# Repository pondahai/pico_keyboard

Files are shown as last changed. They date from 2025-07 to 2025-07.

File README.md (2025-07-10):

# Pico 8x8 矩陣鍵盤韌體

這是一個基於 Raspberry Pi Pico (RP2040) 的 8x8 (64鍵) 自訂機械鍵盤韌體專案。它使用 Arduino-Pico 核心，並透過 74HC595 和 74HC165 晶片來擴展 I/O，僅用 3 個 GPIO 引腳就完成了 64 個按鍵的掃描。此外，還額外擴展了 2 個 LED 指示燈。

韌體最終將 Pico 模擬成一個標準的 USB HID 鍵盤，可以被任何現代作業系統即插即用，同時保留了方便的序列埠除錯功能。

**「這句話就是用這個鍵盤輸入的」** —— 專案成功的最好證明！


## ✨ 主要功能

*   **高效 I/O 擴展**：僅用 3 個 Pico GPIO 引腳驅動 8x8 (64鍵) 矩陣和 2 個 LED。
*   **USB HID 鍵盤**：被電腦識別為標準鍵盤，隨插即用。
*   **複合式 USB 裝置**：同時啟用鍵盤功能和序列埠，方便即時除錯。
*   **雙模式系統**:
    *   **正常打字模式**: 作為一個標準鍵盤工作。
    *   **除錯模式**: 透過序列埠輸出按鍵的物理座標 `(row, col)`，極大地方便了 Keymap 的配置與修改。
*   **韌體層級熱鍵**：使用 `右Shift` + `左Ctrl` 組合鍵在兩種模式間自由切換。
*   **LED 狀態指示**:
    *   LED 1: （目前留空，可自訂，例如用於 CapsLock 指示）。
    *   LED 2: 指示當前是否處於除錯模式（亮起 = 除錯模式）。
*   **全鍵無衝 (NKRO)**：底層支援 6-Key Rollover，可透過修改 HID 報告描述符實現全鍵無衝。
*   **高度客製化**: 使用者可以透過修改 `keymap` 陣列輕鬆定義自己的按鍵佈局。
*   **可靠的掃描邏輯**:
    *   採用「二段式脈衝」確保掃描時序穩定。
    *   第一段脈衝給595輸出 第二段脈衝給165載入 
    *   針對 74HC165 的特性自訂 `shiftIn` 邏輯，避免丟失數據。
    *   對硬體掃描數據進行「水平鏡像」，使 `keymap` 的定義符合物理直覺。

## ⚙️ 硬體需求

### 主要元件
*   Raspberry Pi Pico (或任何 RP2040 開發板)
*   1 x 74HC595 (8位元移位暫存器，用於行掃描輸出)
*   1 x 74HC165 (8位元並行輸入移位暫存器，用於列讀取)
*   2 x D型正反器 (或第二顆 74HC595，用於擴展 LED 輸出)
*   8x8 矩陣鍵盤 (64個按鍵和二極體)
*   2 x LED 指示燈
*   下拉電阻 (為 74HC165 的每個輸入引腳配置)

### GPIO 連接

| Pico GPIO | 連接目標 | 功能描述 |
| :--- | :--- | :--- |
| **GP15**  | 74HC595 的 `DS` (Serial Data In) | 數據輸出 (Pico -> 595) |
| **GP14**  | 74HC595 `RCLK` **和** 74HC165 `nPL` (共用) | 鎖存輸出 (上升緣) / 並行加載輸入 (低電位) |
| **GP26**  | 74HC595 `SHCP` **和** 74HC165 `SHCP` (共用) | 共用的移位時脈 |
| **GP27**  | 74HC165 的 `Q7` (Serial Data Out) | 數據輸入 (165 -> Pico) |

### 晶片串接
*   **輸出鏈 (595)**: `Pico GP15` -> `595(IC1) DS` -> `595(IC1) Q7'` -> `DFF(IC2) D` -> ...
*   **時脈與鎖存**：所有晶片的時脈腳和鎖存腳都並聯到對應的 Pico GPIO。

## 🛠️ 軟體設定與編譯

### Arduino IDE 環境
1.  安裝 **Arduino IDE**。
2.  在「開發板管理器」中，安裝 **Earle F. Philhower, III** 的 **Raspberry Pi Pico/RP2040** 核心。
3.  在 **工具 > 開發板** 中選擇 "Raspberry Pi Pico"。
4.  ~**【最重要的一步】** 在 **工具 > USB Stack** 中，選擇 **"Adafruit TinyUSB"**。這會啟用複合式 USB 裝置功能。~
5.  因為gemini一直堅持使用 **"Adafruit TinyUSB"** 但是HID一直無法正常啟用 因此我去找討論區有人提到標準庫可以支援標準的 Keyboard.h 於是USB Stack就切換回Pico SDK 並且使用標準的 Keyboard.h

### 編譯與上傳
1.  用 Arduino IDE 打開 `.ino` 檔案。
2.  連接 Pico 到電腦。
3.  選擇正確的 COM 連接埠。
4.  點擊「上傳」按鈕。

## ⌨️ 使用說明

1.  **初次連接**: 上傳程式碼後，Pico 將被電腦識別為一個複合式裝置（鍵盤 + 序列埠）。
2.  **預設模式**: 韌體預設進入**除錯模式**。此時 **LED 2** 會亮起。
3.  **除錯模式**:
    *   打開 Arduino IDE 的「序列埠監控器」（鮑率設為 115200）。
    *   按下鍵盤上的任意按鍵。
    *   序列埠監控器會顯示一個 8x8 的狀態矩陣，並打印出被按下按鍵的物理座標，例如 `Key Pressed at: (Row: 2, Col: 6)`。
    *   使用這個功能來確認每個按鍵的座標，以便精確修改下方的 `keymap`。
4.  **切換到正常打字模式**:
    *   同時按下 **右 Shift** 和 **左 Ctrl** 鍵。
    *   **LED 2** 將會熄滅。
    *   現在，您的鍵盤可以像一個普通鍵盤一樣，在任何文字編輯器中輸入文字。
5.  **切換回除錯模式**:
    *   再次同時按下 **右 Shift** 和 **左 Ctrl** 鍵即可。

## 📝 Keymap 客製化

要定義您自己的按鍵佈局，您只需要修改原始碼中的 `keymap_hid` 陣列。

```cpp
const uint8_t keymap_hid[8][8] = {
  // COL 0        1         2         3         4         ...
  {HID_KEY_1, HID_KEY_3, HID_KEY_5, ... }, // ROW 0
  {HID_KEY_Q, HID_KEY_E, HID_KEY_T, ... }, // ROW 1
  // ... and so on
};
```
*   陣列的 `[row][col]` 索引與您在**除錯模式**下看到的座標完全對應。
*   陣列中的值是標準的 **USB HID Usage ID**（也稱為 Scancode）。您可以在程式碼頂部的 `#define` 區域找到常用鍵的定義，或查詢相關的 USB HID 文件。
*   這裡應使用除錯模式 透過序列埠監控器觀察硬體按鍵對應的keymap位置 然後去keymap陣列變數中填入正確對應的按鍵。

## 💡 未來可擴展方向

*   實現多層 Keymap (Fn 層)。
*   加入巨集功能。
*   Tap Dance（輕觸/長按不同功能）。
*   RGB LED 燈光效果。
*   OLED 螢幕狀態顯示。

---

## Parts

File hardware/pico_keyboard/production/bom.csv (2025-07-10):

Designator | Footprint | Quantity | Value | LCSC Part #
C1, C2, C3 | 0805 | 3 | 100n
D1, D10, D11, D12, D13, D14, D15, D16, D17, D18, D19, D2, D20, D21, D22, D23, D24, D25, D26, D27, D28, D29, D3, D30, D31, D32, D33, D34, D35, D36, D37, D38, D39, D4, D40, D41, D42, D43, D44, D45, D46, D47, D48, D49, D5, D50, D51, D52, D53, D54, D55, D56, D57, D58, D59, D6, D60, D61, D62, D7, D8, D9 | D_DO-35_SOD27_SOD123_P7.62mm_Horizontal | 62 | 1N4148
D63 | LED_D3.0mm_Clear | 1 | ㄅ
D64 | LED_D3.0mm_Clear | 1 | ENG
J1 | PinHeader_1x07_P2.54mm_Horizontal | 1 | Conn_01x07
R1, R2 | R_Axial_DIN0204_L3.6mm_D1.6mm_P7.62mm_Horizontal_0805 | 2 | R_US
RN1, RN2 | R_Array_Convex_4x0603 | 2 | 10K
SW1 | SW_Push_1P1T_NO_CK_KSC7xxJ | 1 | 1!ㄅ
SW10 | SW_Push_1P1T_NO_CK_KSC7xxJ | 1 | Eㄍ
SW11 | SW_Push_1P1T_NO_CK_KSC7xxJ | 1 | Dㄎ
SW12 | SW_Push_1P1T_NO_CK_KSC7xxJ | 1 | Cㄏ
SW13 | SW_Push_1P1T_NO_CK_KSC7xxJ | 1 | 4$ˋ
SW14 | SW_Push_1P1T_NO_CK_KSC7xxJ | 1 | Rㄐ
SW15 | SW_Push_1P1T_NO_CK_KSC7xxJ | 1 | Fㄑ
SW16 | SW_Push_1P1T_NO_CK_KSC7xxJ | 1 | Vㄒ
SW17 | SW_Push_1P1T_NO_CK_KSC7xxJ | 1 | 5%ㄓ
SW18 | SW_Push_1P1T_NO_CK_KSC7xxJ | 1 | Tㄔ
SW19 | SW_Push_1P1T_NO_CK_KSC7xxJ | 1 | Gㄕ
SW2 | SW_Push_1P1T_NO_CK_KSC7xxJ | 1 | Qㄆ
SW20 | SW_Push_1P1T_NO_CK_KSC7xxJ | 1 | Bㄖ
SW21 | SW_Push_1P1T_NO_CK_KSC7xxJ | 1 | 6^ˊ
SW22 | SW_Push_1P1T_NO_CK_KSC7xxJ | 1 | Yㄗ
SW23 | SW_Push_1P1T_NO_CK_KSC7xxJ | 1 | Hㄘ
SW24 | SW_Push_1P1T_NO_CK_KSC7xxJ | 1 | Nㄙ
SW25 | SW_Push_1P1T_NO_CK_KSC7xxJ | 1 | 7&˙
SW26 | SW_Push_1P1T_NO_CK_KSC7xxJ | 1 | Uㄧ
SW27 | SW_Push_1P1T_NO_CK_KSC7xxJ | 1 | Jㄨ
SW28 | SW_Push_1P1T_NO_CK_KSC7xxJ | 1 | Mㄩ
SW29 | SW_Push_1P1T_NO_CK_KSC7xxJ | 1 | 8*ㄚ
SW3 | SW_Push_1P1T_NO_CK_KSC7xxJ | 1 | Aㄇ
SW30 | SW_Push_1P1T_NO_CK_KSC7xxJ | 1 | Iㄛ
SW31 | SW_Push_1P1T_NO_CK_KSC7xxJ | 1 | Kㄜ
SW32 | SW_Push_1P1T_NO_CK_KSC7xxJ | 1 | ,<ㄝ
SW33 | SW_Push_1P1T_NO_CK_KSC7xxJ | 1 | 9(ㄞ
SW34 | SW_Push_1P1T_NO_CK_KSC7xxJ | 1 | Oㄟ
SW35 | SW_Push_1P1T_NO_CK_KSC7xxJ | 1 | Lㄠ
SW36 | SW_Push_1P1T_NO_CK_KSC7xxJ | 1 | .>ㄡ
SW37 | SW_Push_1P1T_NO_CK_KSC7xxJ | 1 | 0)ㄢ
SW38 | SW_Push_1P1T_NO_CK_KSC7xxJ | 1 | Pㄣ
SW39 | SW_Push_1P1T_NO_CK_KSC7xxJ | 1 | ;:ㄤ
SW4 | SW_Push_1P1T_NO_CK_KSC7xxJ | 1 | Zㄈ
SW40 | SW_Push_1P1T_NO_CK_KSC7xxJ | 1 | /?ㄥ
SW41 | SW_Push_1P1T_NO_CK_KSC7xxJ | 1 | -_ㄦ
SW42 | SW_Push_1P1T_NO_CK_KSC7xxJ | 1 | [{
SW43 | SW_Push_1P1T_NO_CK_KSC7xxJ | 1 | '"
SW44 | SW_Push_1P1T_NO_CK_KSC7xxJ | 1 | SHIFT
SW45 | SW_Push_1P1T_NO_CK_KSC7xxJ | 1 | =+
SW46 | SW_Push_1P1T_NO_CK_KSC7xxJ | 1 | ]}
SW47 | SW_Push_1P1T_NO_CK_KSC7xxJ | 1 | ENTER
SW48 | SW_Push_1P1T_NO_CK_KSC7xxJ | 1 | SPACE
SW49 | SW_Push_1P1T_NO_CK_KSC7xxJ | 1 | `~
SW5 | SW_Push_1P1T_NO_CK_KSC7xxJ | 1 | 2@ㄉ
SW50 | SW_Push_1P1T_NO_CK_KSC7xxJ | 1 | TAB
SW51 | SW_Push_1P1T_NO_CK_KSC7xxJ | 1 | CAPS
SW52 | SW_Push_1P1T_NO_CK_KSC7xxJ | 1 | CTRL
SW53 | SW_Push_1P1T_NO_CK_KSC7xxJ | 1 | ALT
SW54 | SW_Push_1P1T_NO_CK_KSC7xxJ | 1 | BACK
SW55 | SW_Push_1P1T_NO_CK_KSC7xxJ | 1 | \
SW56 | SW_Push_1P1T_NO_CK_KSC7xxJ | 1 | PGUP
SW57 | SW_Push_1P1T_NO_CK_KSC7xxJ | 1 | PGDN
SW58 | SW_Push_1P1T_NO_CK_KSC7xxJ | 1 | UP
SW59 | SW_Push_1P1T_NO_CK_KSC7xxJ | 1 | DOWN
SW6 | SW_Push_1P1T_NO_CK_KSC7xxJ | 1 | Wㄊ
SW60 | SW_Push_1P1T_NO_CK_KSC7xxJ | 1 | LEFT
SW61 | SW_Push_1P1T_NO_CK_KSC7xxJ | 1 | RGHT
SW62 | SW_Push_1P1T_NO_CK_KSC7xxJ | 1 | ESC
SW7 | SW_Push_1P1T_NO_CK_KSC7xxJ | 1 | Sㄋ
SW8 | SW_Push_1P1T_NO_CK_KSC7xxJ | 1 | Xㄌ
SW9 | SW_Push_1P1T_NO_CK_KSC7xxJ | 1 | 3#ˇ
U1 | SOIC-16_3.9x9.9mm_P1.27mm | 1 | 74HC595
U2 | SOIC-16_3.9x9.9mm_P1.27mm | 1 | 74HC165
U3 | SO-14_3.9x8.65mm_P1.27mm | 1 | 74HCT74

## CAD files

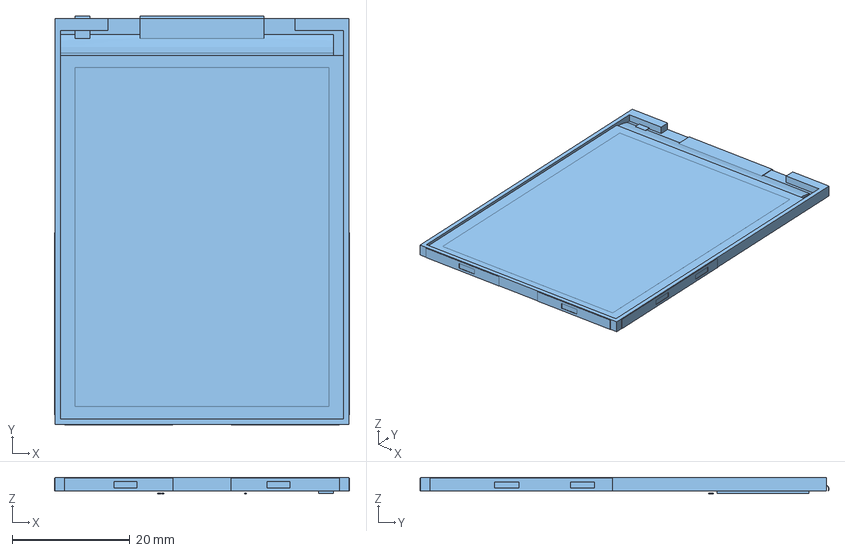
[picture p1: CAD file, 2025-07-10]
hardware/pico_keyboard/2.8 TFT Module001.5.step
50.1 x 69.5 x 2.72 mm

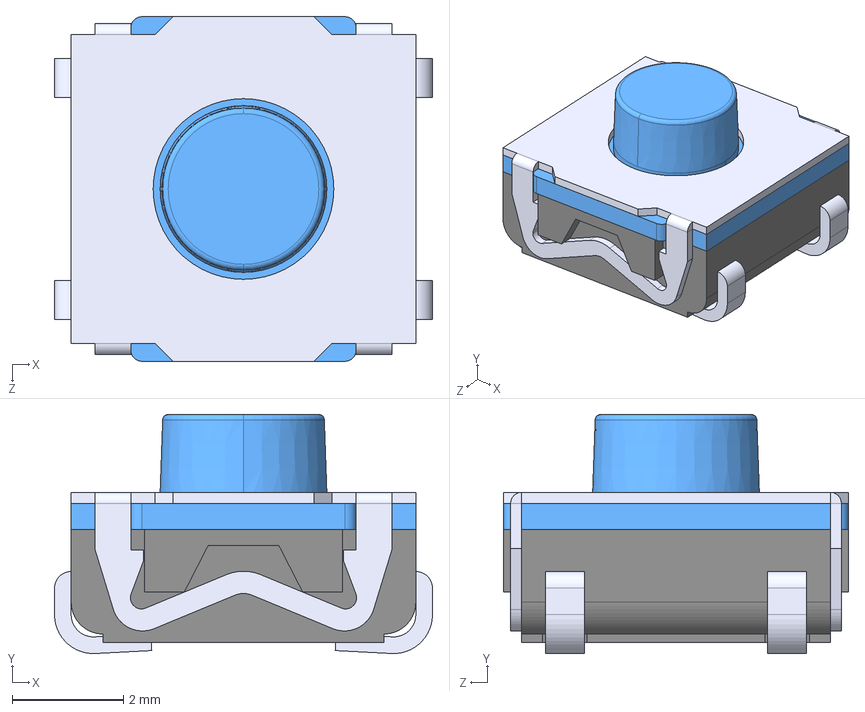
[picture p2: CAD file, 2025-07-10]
hardware/pico_keyboard/KSC741J LFS.STEP
6.80 x 4.30 x 6.20 mm

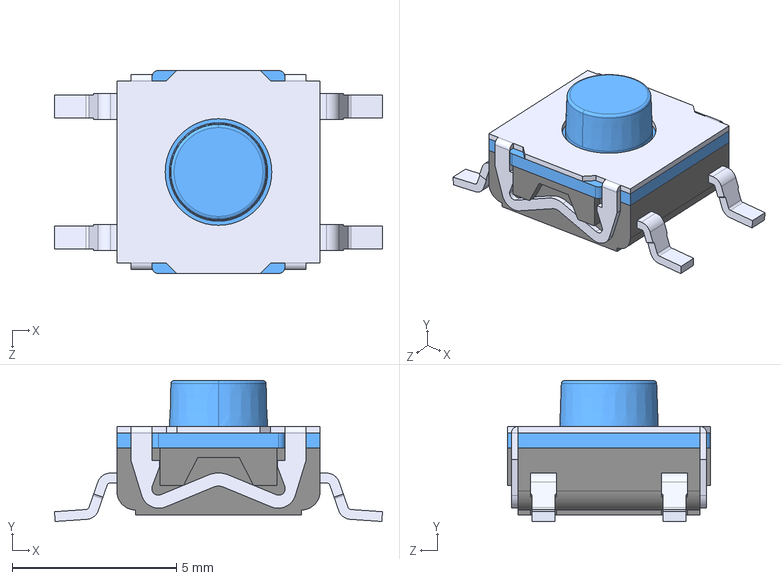
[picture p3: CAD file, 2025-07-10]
hardware/pico_keyboard/KSC741G LFS.STEP
10.0 x 4.30 x 6.20 mm

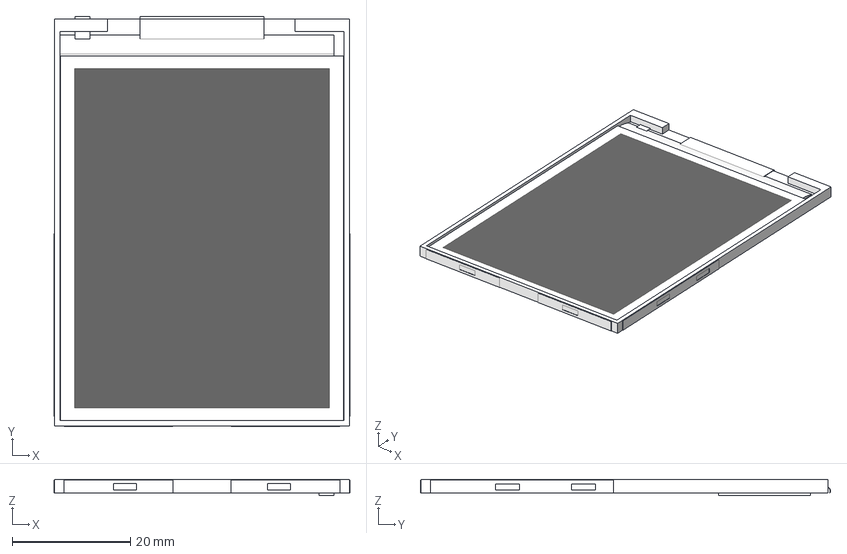
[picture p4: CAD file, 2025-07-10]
hardware/pico_keyboard/2.8 TFT Module001.007.0.step
50.1 x 69.5 x 2.72 mm
2.8 TFT Module001.007.0.0
2.8 TFT Module001.007.0.1
2.8 TFT Module001.007.0.2
2.8 TFT Module001.007.0.3
2.8 TFT Module001.007.0.4
2.8 TFT Module001.007.0.5
2.8 TFT Module001.007.0.6
2.8 TFT Module001.007.0.7
2.8 TFT Module001.007.0.8
2.8 TFT Module001.007.0.9
2.8 TFT Module001.007.0.10
2.8 TFT Module001.007.0.11
2.8 TFT Module001.007.0.12
2.8 TFT Module001.007.0.13
2.8 TFT Module001.007.0.14
2.8 TFT Module001.007.0.15
2.8 TFT Module001.007.0.16
2.8 TFT Module001.007.0.17
2.8 TFT Module001.007.0.18
2.8 TFT Module001.007.0.19
2.8 TFT Module001.007.0.20
2.8 TFT Module001.007.0.21
2.8 TFT Module001.007.0.22
2.8 TFT Module001.007.0.23
2.8 TFT Module001.007.0.24
2.8 TFT Module001.007.0.25
2.8 TFT Module001.007.0.26
2.8 TFT Module001.007.0.27
2.8 TFT Module001.007.0.28
2.8 TFT Module001.007.0.29
2.8 TFT Module001.007.0.30
2.8 TFT Module001.007.0.31
2.8 TFT Module001.007.0.32
2.8 TFT Module001.007.0.33
2.8 TFT Module001.007.0.34
2.8 TFT Module001.007.0.35
2.8 TFT Module001.007.0.36
2.8 TFT Module001.007.0.37
2.8 TFT Module001.007.0.38
2.8 TFT Module001.007.0.39
2.8 TFT Module001.007.0.40
2.8 TFT Module001.007.0.41
2.8 TFT Module001.007.0.42
2.8 TFT Module001.007.0.43
2.8 TFT Module001.007.0.44
2.8 TFT Module001.007.0.45
2.8 TFT Module001.007.0.46
2.8 TFT Module001.007.0.47
2.8 TFT Module001.007.0.48
2.8 TFT Module001.007.0.49
2.8 TFT Module001.007.0.50
2.8 TFT Module001.007.0.51
2.8 TFT Module001.007.0.52
2.8 TFT Module001.007.0.53
2.8 TFT Module001.007.0.54
2.8 TFT Module001.007.0.55
2.8 TFT Module001.007.0.56
2.8 TFT Module001.007.0.57
2.8 TFT Module001.007.0.58
2.8 TFT Module001.007.0.59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

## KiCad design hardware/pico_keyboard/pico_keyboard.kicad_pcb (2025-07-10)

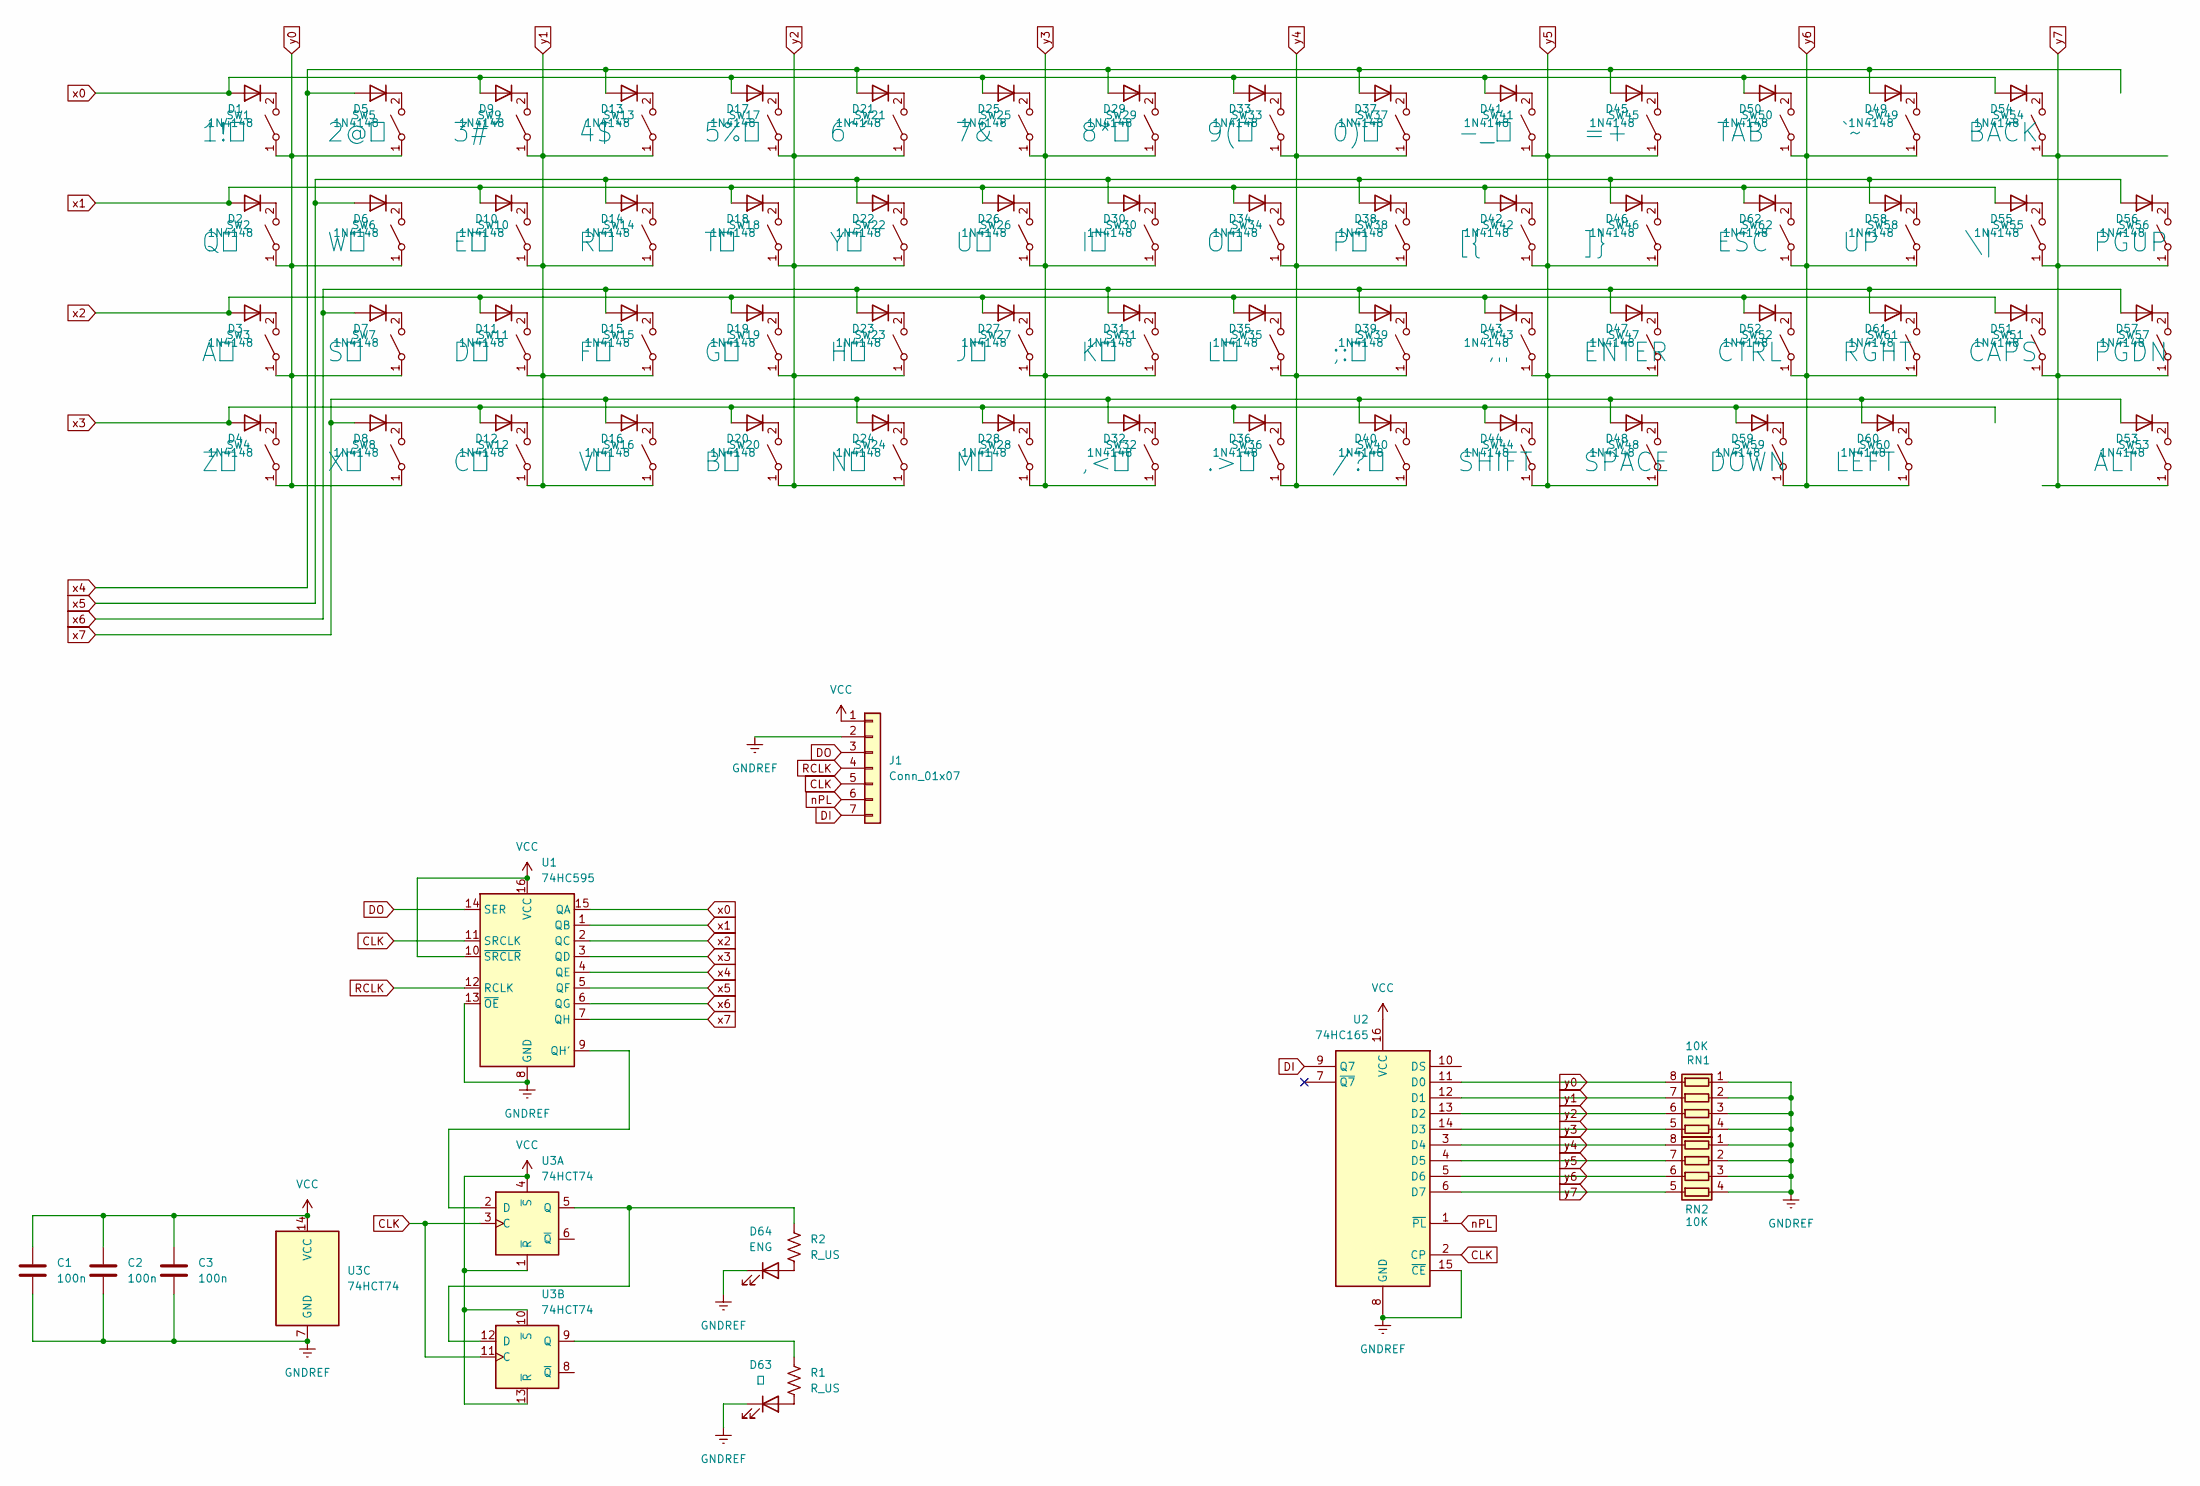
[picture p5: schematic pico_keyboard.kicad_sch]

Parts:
C1, C2, C3: 100n; C_0805_2012Metric_Pad1.18x1.45mm_HandSolder
D1, D2, D3, D4, D5, D6, D7, D8, D9, D10, D11, D12, D13, D14, D15, D16, D17, D18, D19, D20, D21, D22, D23, D24, D25, D26, D27, D28, D29, D30, D31, D32, D33, D34, D35, D36, D37, D38, D39, D40, D41, D42, D43, D44, D45, D46, D47, D48, D49, D50, D51, D52, D53, D54, D55, D56, D57, D58, D59, D60, D61, D62: 1N4148; D_DO-35_SOD27_SOD123_P7.62mm_Horizontal
D63: ㄅ; LED_D3.0mm_Clear
D64: ENG; LED_D3.0mm_Clear
J1: Conn_01x07; PinHeader_1x07_P2.54mm_Horizontal
R1, R2: R_US; R_Axial_DIN0204_L3.6mm_D1.6mm_P7.62mm_Horizontal_0805
RN1, RN2: 10K; R_Array_Convex_4x0603
SW1: 1!ㄅ; SW_Push_1P1T_NO_CK_KSC7xxJ
SW2: Qㄆ; SW_Push_1P1T_NO_CK_KSC7xxJ
SW3: Aㄇ; SW_Push_1P1T_NO_CK_KSC7xxJ
SW4: Zㄈ; SW_Push_1P1T_NO_CK_KSC7xxJ
SW5: 2@ㄉ; SW_Push_1P1T_NO_CK_KSC7xxJ
SW6: Wㄊ; SW_Push_1P1T_NO_CK_KSC7xxJ
SW7: Sㄋ; SW_Push_1P1T_NO_CK_KSC7xxJ
SW8: Xㄌ; SW_Push_1P1T_NO_CK_KSC7xxJ
SW9: 3#ˇ; SW_Push_1P1T_NO_CK_KSC7xxJ
SW10: Eㄍ; SW_Push_1P1T_NO_CK_KSC7xxJ
SW11: Dㄎ; SW_Push_1P1T_NO_CK_KSC7xxJ
SW12: Cㄏ; SW_Push_1P1T_NO_CK_KSC7xxJ
SW13: 4$ˋ; SW_Push_1P1T_NO_CK_KSC7xxJ
SW14: Rㄐ; SW_Push_1P1T_NO_CK_KSC7xxJ
SW15: Fㄑ; SW_Push_1P1T_NO_CK_KSC7xxJ
SW16: Vㄒ; SW_Push_1P1T_NO_CK_KSC7xxJ
SW17: 5%ㄓ; SW_Push_1P1T_NO_CK_KSC7xxJ
SW18: Tㄔ; SW_Push_1P1T_NO_CK_KSC7xxJ
SW19: Gㄕ; SW_Push_1P1T_NO_CK_KSC7xxJ
SW20: Bㄖ; SW_Push_1P1T_NO_CK_KSC7xxJ
SW21: 6^ˊ; SW_Push_1P1T_NO_CK_KSC7xxJ
SW22: Yㄗ; SW_Push_1P1T_NO_CK_KSC7xxJ
SW23: Hㄘ; SW_Push_1P1T_NO_CK_KSC7xxJ
SW24: Nㄙ; SW_Push_1P1T_NO_CK_KSC7xxJ
SW25: 7&˙; SW_Push_1P1T_NO_CK_KSC7xxJ
SW26: Uㄧ; SW_Push_1P1T_NO_CK_KSC7xxJ
SW27: Jㄨ; SW_Push_1P1T_NO_CK_KSC7xxJ
SW28: Mㄩ; SW_Push_1P1T_NO_CK_KSC7xxJ
SW29: 8*ㄚ; SW_Push_1P1T_NO_CK_KSC7xxJ
SW30: Iㄛ; SW_Push_1P1T_NO_CK_KSC7xxJ
SW31: Kㄜ; SW_Push_1P1T_NO_CK_KSC7xxJ
SW32: ,<ㄝ; SW_Push_1P1T_NO_CK_KSC7xxJ
SW33: 9(ㄞ; SW_Push_1P1T_NO_CK_KSC7xxJ
SW34: Oㄟ; SW_Push_1P1T_NO_CK_KSC7xxJ
SW35: Lㄠ; SW_Push_1P1T_NO_CK_KSC7xxJ
SW36: .>ㄡ; SW_Push_1P1T_NO_CK_KSC7xxJ
SW37: 0)ㄢ; SW_Push_1P1T_NO_CK_KSC7xxJ
SW38: Pㄣ; SW_Push_1P1T_NO_CK_KSC7xxJ
SW39: ;:ㄤ; SW_Push_1P1T_NO_CK_KSC7xxJ
SW40: /?ㄥ; SW_Push_1P1T_NO_CK_KSC7xxJ
SW41: -_ㄦ; SW_Push_1P1T_NO_CK_KSC7xxJ
SW42: [{; SW_Push_1P1T_NO_CK_KSC7xxJ
SW43: '"; SW_Push_1P1T_NO_CK_KSC7xxJ
SW44: SHIFT; SW_Push_1P1T_NO_CK_KSC7xxJ
SW45: =+; SW_Push_1P1T_NO_CK_KSC7xxJ
SW46: ]}; SW_Push_1P1T_NO_CK_KSC7xxJ
SW47: ENTER; SW_Push_1P1T_NO_CK_KSC7xxJ
SW48: SPACE; SW_Push_1P1T_NO_CK_KSC7xxJ
SW49: `~; SW_Push_1P1T_NO_CK_KSC7xxJ
SW50: TAB; SW_Push_1P1T_NO_CK_KSC7xxJ
SW51: CAPS; SW_Push_1P1T_NO_CK_KSC7xxJ
SW52: CTRL; SW_Push_1P1T_NO_CK_KSC7xxJ
SW53: ALT; SW_Push_1P1T_NO_CK_KSC7xxJ
SW54: BACK; SW_Push_1P1T_NO_CK_KSC7xxJ
SW55: \|; SW_Push_1P1T_NO_CK_KSC7xxJ
SW56: PGUP; SW_Push_1P1T_NO_CK_KSC7xxJ
SW57: PGDN; SW_Push_1P1T_NO_CK_KSC7xxJ
SW58: UP; SW_Push_1P1T_NO_CK_KSC7xxJ
SW59: DOWN; SW_Push_1P1T_NO_CK_KSC7xxJ
SW60: LEFT; SW_Push_1P1T_NO_CK_KSC7xxJ
SW61: RGHT; SW_Push_1P1T_NO_CK_KSC7xxJ
SW62: ESC; SW_Push_1P1T_NO_CK_KSC7xxJ
U1: 74HC595; SOIC-16_3.9x9.9mm_P1.27mm
U2: 74HC165; SOIC-16_3.9x9.9mm_P1.27mm
U3: 74HCT74; SO-14_3.9x8.65mm_P1.27mm

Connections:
CLK: J1.5, U1.11 (SRCLK), U2.2 (CP), U3.3 (C), U3.11 (C)
DI: J1.7, U2.9 (Q7)
DO: J1.3, U1.14 (SER)
GNDREF: C1.2, C2.2, C3.2, D63.1 (K), D64.1 (K), J1.2, RN1.1 (R1.1), RN1.2 (R2.1), RN1.3 (R3.1), RN1.4 (R4.1), RN2.1 (R1.1), RN2.2 (R2.1), RN2.3 (R3.1), RN2.4 (R4.1), U1.8 (GND), U1.13 (~OE), U2.8 (GND), U2.15 (~CE), U3.7 (GND)
unnamed: D1.1 (K), SW1.2 (B)
unnamed: D2.1 (K), SW2.2 (B)
unnamed: D3.1 (K), SW3.2 (B)
unnamed: D4.1 (K), SW4.2 (B)
unnamed: D5.1 (K), SW5.2 (B)
unnamed: D6.1 (K), SW6.2 (B)
unnamed: D7.1 (K), SW7.2 (B)
unnamed: D8.1 (K), SW8.2 (B)
unnamed: D9.1 (K), SW9.2 (B)
unnamed: D10.1 (K), SW10.2 (B)
unnamed: D11.1 (K), SW11.2 (B)
unnamed: D12.1 (K), SW12.2 (B)
unnamed: D13.1 (K), SW13.2 (B)
unnamed: D14.1 (K), SW14.2 (B)
unnamed: D15.1 (K), SW15.2 (B)
unnamed: D16.1 (K), SW16.2 (B)
unnamed: D17.1 (K), SW17.2 (B)
unnamed: D18.1 (K), SW18.2 (B)
unnamed: D19.1 (K), SW19.2 (B)
unnamed: D20.1 (K), SW20.2 (B)
unnamed: D21.1 (K), SW21.2 (B)
unnamed: D22.1 (K), SW22.2 (B)
unnamed: D23.1 (K), SW23.2 (B)
unnamed: D24.1 (K), SW24.2 (B)
unnamed: D25.1 (K), SW25.2 (B)
unnamed: D26.1 (K), SW26.2 (B)
unnamed: D27.1 (K), SW27.2 (B)
unnamed: D28.1 (K), SW28.2 (B)
unnamed: D29.1 (K), SW29.2 (B)
unnamed: D30.1 (K), SW30.2 (B)
unnamed: D31.1 (K), SW31.2 (B)
unnamed: D32.1 (K), SW32.2 (B)
unnamed: D33.1 (K), SW33.2 (B)
unnamed: D34.1 (K), SW34.2 (B)
unnamed: D35.1 (K), SW35.2 (B)
unnamed: D36.1 (K), SW36.2 (B)
unnamed: D37.1 (K), SW37.2 (B)
unnamed: D38.1 (K), SW38.2 (B)
unnamed: D39.1 (K), SW39.2 (B)
unnamed: D40.1 (K), SW40.2 (B)
unnamed: D41.1 (K), SW41.2 (B)
unnamed: D42.1 (K), SW42.2 (B)
unnamed: D43.1 (K), SW43.2 (B)
unnamed: D44.1 (K), SW44.2 (B)
unnamed: D45.1 (K), SW45.2 (B)
unnamed: D46.1 (K), SW46.2 (B)
unnamed: D47.1 (K), SW47.2 (B)
unnamed: D48.1 (K), SW48.2 (B)
unnamed: D49.1 (K), SW49.2 (B)
unnamed: D50.1 (K), SW50.2 (B)
unnamed: D51.1 (K), SW51.2 (B)
unnamed: D52.1 (K), SW52.2 (B)
unnamed: D53.1 (K), SW53.2 (B)
unnamed: D54.1 (K), SW54.2 (B)
unnamed: D55.1 (K), SW55.2 (B)
unnamed: D56.1 (K), SW56.2 (B)
unnamed: D57.1 (K), SW57.2 (B)
unnamed: D58.1 (K), SW58.2 (B)
unnamed: D59.1 (K), SW59.2 (B)
unnamed: D60.1 (K), SW60.2 (B)
unnamed: D61.1 (K), SW61.2 (B)
unnamed: D62.1 (K), SW62.2 (B)
unnamed: D63.2 (A), R1.2
unnamed: D64.2 (A), R2.2
unnamed: U1.9 (QH'), U3.2 (D)
unnamed: R2.1, U3.5 (Q), U3.12 (D)
unnamed: R1.1, U3.9 (Q)
RCLK: J1.4, U1.12 (RCLK)
VCC: C1.1, C2.1, C3.1, J1.1, U1.10 (~SRCLR), U1.16 (VCC), U2.16 (VCC), U3.1 (~R), U3.4 (~S), U3.10 (~S), U3.13 (~R), U3.14 (VCC)
nPL: J1.6, U2.1 (~PL)
x0: D1.2 (A), D9.2 (A), D17.2 (A), D25.2 (A), D33.2 (A), D41.2 (A), D50.2 (A), D54.2 (A), U1.15 (QA)
x1: D2.2 (A), D10.2 (A), D18.2 (A), D26.2 (A), D34.2 (A), D42.2 (A), D55.2 (A), D62.2 (A), U1.1 (QB)
x2: D3.2 (A), D11.2 (A), D19.2 (A), D27.2 (A), D35.2 (A), D43.2 (A), D51.2 (A), D52.2 (A), U1.2 (QC)
x3: D4.2 (A), D12.2 (A), D20.2 (A), D28.2 (A), D36.2 (A), D44.2 (A), D59.2 (A), U1.3 (QD)
x4: D5.2 (A), D13.2 (A), D21.2 (A), D29.2 (A), D37.2 (A), D45.2 (A), D49.2 (A), U1.4 (QE)
x5: D6.2 (A), D14.2 (A), D22.2 (A), D30.2 (A), D38.2 (A), D46.2 (A), D56.2 (A), D58.2 (A), U1.5 (QF)
x6: D7.2 (A), D15.2 (A), D23.2 (A), D31.2 (A), D39.2 (A), D47.2 (A), D57.2 (A), D61.2 (A), U1.6 (QG)
x7: D8.2 (A), D16.2 (A), D24.2 (A), D32.2 (A), D40.2 (A), D48.2 (A), D53.2 (A), D60.2 (A), U1.7 (QH)
y0: RN1.8 (R1.2), SW1.1 (A), SW2.1 (A), SW3.1 (A), SW4.1 (A), SW5.1 (A), SW6.1 (A), SW7.1 (A), SW8.1 (A), U2.11 (D0)
y1: RN1.7 (R2.2), SW9.1 (A), SW10.1 (A), SW11.1 (A), SW12.1 (A), SW13.1 (A), SW14.1 (A), SW15.1 (A), SW16.1 (A), U2.12 (D1)
y2: RN1.6 (R3.2), SW17.1 (A), SW18.1 (A), SW19.1 (A), SW20.1 (A), SW21.1 (A), SW22.1 (A), SW23.1 (A), SW24.1 (A), U2.13 (D2)
y3: RN1.5 (R4.2), SW25.1 (A), SW26.1 (A), SW27.1 (A), SW28.1 (A), SW29.1 (A), SW30.1 (A), SW31.1 (A), SW32.1 (A), U2.14 (D3)
y4: RN2.8 (R1.2), SW33.1 (A), SW34.1 (A), SW35.1 (A), SW36.1 (A), SW37.1 (A), SW38.1 (A), SW39.1 (A), SW40.1 (A), U2.3 (D4)
y5: RN2.7 (R2.2), SW41.1 (A), SW42.1 (A), SW43.1 (A), SW44.1 (A), SW45.1 (A), SW46.1 (A), SW47.1 (A), SW48.1 (A), U2.4 (D5)
y6: RN2.6 (R3.2), SW49.1 (A), SW50.1 (A), SW52.1 (A), SW58.1 (A), SW59.1 (A), SW60.1 (A), SW61.1 (A), SW62.1 (A), U2.5 (D6)
y7: RN2.5 (R4.2), SW51.1 (A), SW53.1 (A), SW54.1 (A), SW55.1 (A), SW56.1 (A), SW57.1 (A), U2.6 (D7)

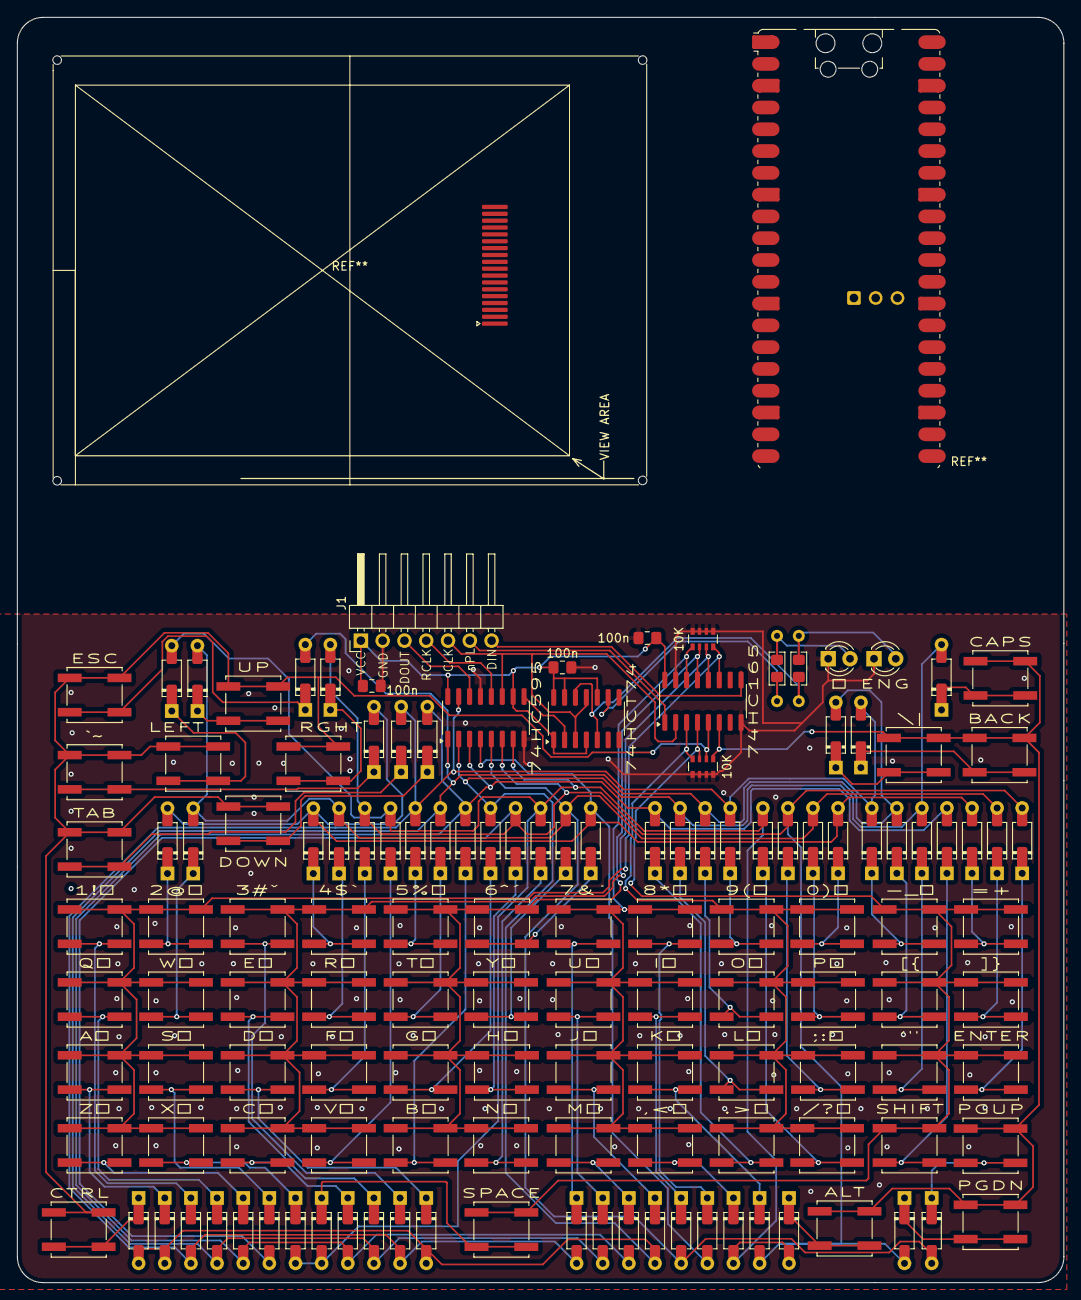
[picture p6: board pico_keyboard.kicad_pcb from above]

Board: 2 copper layers, 122.0 x 147.5 mm, 137 parts (0 on the bottom side), 90 nets.

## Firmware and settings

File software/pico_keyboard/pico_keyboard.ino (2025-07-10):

#include <Arduino.h>

// --- 硬體引腳定義 ---
const int DATA_OUT_PIN = 15;
const int LATCH_PIN    = 14;
const int CLOCK_PIN    = 26;
const int DATA_IN_PIN  = 27;

// --- 按鍵轉換設定 ---
// 1. 定義功能鍵碼 (新增 KEY_ALT)
#define KEY_NULL        0
#define KEY_SHIFT_R   202
#define KEY_ENTER     203
#define KEY_BACKSPACE 204
#define KEY_CTRL_L    205
#define KEY_TAB       206
#define KEY_ESC       207
#define KEY_CAPS_LOCK 208
#define KEY_UP_ARROW  209
#define KEY_DOWN_ARROW 210
#define KEY_LEFT_ARROW 211
#define KEY_RIGHT_ARROW 212
#define KEY_PGUP      213
#define KEY_PGDOWN    214
#define KEY_ALT       215  // *** 新增 ***

// 2. Keymap 表格 (您提供的最終版本)
const char keymap_base[8][8] = {
  // COL 0        1         2         3         4         5         6         7
  {'1', '3', '5', '7', '9', '-', KEY_TAB, KEY_BACKSPACE},
  {'q', 'e', 't', 'u', 'o', '[', KEY_ESC, '\\'},
  {'a', 'd', 'g', 'j', 'l', '\'', KEY_CTRL_L, KEY_CAPS_LOCK},
  {'z', 'c', 'b', 'm', '.', KEY_SHIFT_R, KEY_DOWN_ARROW, KEY_NULL},
  {'2', '4', '6', '8', '0', '=', '`', KEY_NULL},
  {'w', 'r', 'y', 'i', 'p', ']', KEY_UP_ARROW, KEY_PGUP},
  {'s', 'f', 'h', 'k', ';', KEY_ENTER, KEY_RIGHT_ARROW, KEY_PGDOWN},
  {'x', 'v', 'n', ',', '/', ' ', KEY_LEFT_ARROW, KEY_ALT}
};

const char keymap_shifted[8][8] = {
  // COL 0        1         2         3         4         5         6         7
  {'!', '#', '%', '&', '(', '_', '-', KEY_BACKSPACE},
  {'Q', 'E', 'T', 'U', 'O', '{', KEY_ESC, '\\'},
  {'A', 'D', 'G', 'J', 'L', '"', KEY_CTRL_L, KEY_CAPS_LOCK},
  {'Z', 'C', 'B', 'M', '>', KEY_SHIFT_R, KEY_DOWN_ARROW, KEY_NULL},
  {'@', '$', '^', '*', ')', '+', '~', KEY_NULL},
  {'W', 'R', 'Y', 'I', 'P', '}', KEY_UP_ARROW, KEY_PGUP},
  {'S', 'F', 'H', 'K', ':', KEY_ENTER, KEY_RIGHT_ARROW, KEY_PGDOWN},
  {'X', 'V', 'N', '<', '?', ' ', KEY_LEFT_ARROW, KEY_ALT}
};


// --- 全域變數 ---
bool ledState[2] = {false, false};
bool keyState[8][8];
bool lastKeyState[8][8];
bool isShiftPressed = false;
bool isCapsLockOn = false;
bool isAltPressed = false; // *** 新增 ***
bool debugMode = true;

// --- 函式原型宣告 ---
void updateKeyboardAndLeds_TwoPulse();
byte myShiftIn(uint8_t dataPin, uint8_t clockPin);
void processKeyEvent(int r, int c, bool isPressed);
void printKeyboardStateMatrix();

void setup() {
  Serial.begin(115200);
  while (!Serial);
  Serial.println("\n--- Final Keyboard Firmware with ALT key ---");
  Serial.println("Keymap updated. Defaulting to DEBUG MODE.");
  Serial.println("Press Right_Shift + Ctrl to toggle mode.");

  pinMode(DATA_OUT_PIN, OUTPUT);
  pinMode(LATCH_PIN,    OUTPUT);
  pinMode(CLOCK_PIN,    OUTPUT);
  pinMode(DATA_IN_PIN,  INPUT);

  digitalWrite(LATCH_PIN, LOW);
  digitalWrite(CLOCK_PIN, LOW);
  
  updateKeyboardAndLeds_TwoPulse();
  memcpy(lastKeyState, keyState, sizeof(keyState));
}

void loop() {
  updateKeyboardAndLeds_TwoPulse();

  for (int r = 0; r < 8; r++) {
    for (int c = 0; c < 8; c++) {
      if (keyState[r][c] != lastKeyState[r][c]) {
        processKeyEvent(r, c, keyState[r][c]);
      }
    }
  }

  // LED 1 指示 Caps Lock, LED 2 指示 Debug Mode
  ledState[0] = isCapsLockOn;
  ledState[1] = debugMode; 

  byte ledData = 0;
  if (ledState[0]) bitSet(ledData, 0);
  if (ledState[1]) bitSet(ledData, 1);
  byte rowScanData = 0x00;
  digitalWrite(LATCH_PIN, LOW);
  shiftOut(DATA_OUT_PIN, CLOCK_PIN, MSBFIRST, ledData);
  shiftOut(DATA_OUT_PIN, CLOCK_PIN, MSBFIRST, rowScanData);
  digitalWrite(LATCH_PIN, HIGH);

  memcpy(lastKeyState, keyState, sizeof(keyState));
  delay(10);
}

/**
 * @brief 處理單個按鍵事件的核心函數
 */
void processKeyEvent(int r, int c, bool isPressed) {
  // --- 模式切換檢查 ---
  if (isPressed) {
    bool ctrl_l_pressed = keyState[2][6];
    bool shift_r_pressed = keyState[3][5];
    
    if ((keymap_base[r][c] == KEY_CTRL_L && shift_r_pressed) || 
        (keymap_base[r][c] == KEY_SHIFT_R && ctrl_l_pressed)) {
      debugMode = !debugMode;
      Serial.print("\n\n--- Switched to "); Serial.print(debugMode ? "DEBUG MODE" : "NORMAL TYPING MODE"); Serial.println(" ---\n");
      isShiftPressed = false;
      return; 
    }
  }

  // --- 根據模式選擇行為 ---
  if (debugMode) {
    if (isPressed) { printKeyboardStateMatrix(); Serial.print("Key Pressed: ("); Serial.print(r); Serial.print(","); Serial.print(c); Serial.println(")");} 
    else { printKeyboardStateMatrix(); }
  } else {
    // === 正常打字模式 ===
    bool isLetter = (keymap_base[r][c] >= 'a' && keymap_base[r][c] <= 'z');
    bool shouldBeCapital = isShiftPressed ^ isCapsLockOn;
    
    char keyCode;
    if (isLetter && shouldBeCapital) {
      keyCode = keymap_shifted[r][c];
    } else {
      keyCode = isShiftPressed ? keymap_shifted[r][c] : keymap_base[r][c];
    }

    // --- 處理功能鍵 (按下時) ---
    if (isPressed) {
      switch (keymap_base[r][c]) { // 使用 base 表來識別功能鍵
        case KEY_CAPS_LOCK: isCapsLockOn = !isCapsLockOn; Serial.print("[CapsLock "); Serial.print(isCapsLockOn ? "ON" : "OFF"); Serial.print("]"); return;
        case KEY_ESC: Serial.print("[ESC]"); return;
        case KEY_TAB: Serial.print(isShiftPressed ? "-" : "\t"); return;
        case KEY_UP_ARROW: Serial.print("[UP]"); return;
        case KEY_DOWN_ARROW: Serial.print("[DOWN]"); return;
        case KEY_LEFT_ARROW: Serial.print("[LEFT]"); return;
        case KEY_RIGHT_ARROW: Serial.print("[RIGHT]"); return;
        case KEY_PGUP: Serial.print("[PGUP]"); return;
        case KEY_PGDOWN: Serial.print("[PGDN]"); return;
      }
    }

    // --- 處理修飾鍵和常規按鍵 ---
    // *** 修改: 新增對 KEY_ALT 的處理 ***
    switch (keyCode) {
      case KEY_SHIFT_R: isShiftPressed = isPressed; return;
      case KEY_CTRL_L: /* 可以在此添加對 Ctrl 的處理 */ return;
      case KEY_ALT: isAltPressed = isPressed; Serial.print(isPressed ? "[ALT down]" : "[ALT up]"); return;
    }

    if (isPressed) {
      // 在此處可以添加對 ALT+Key 組合的處理
      if (isAltPressed) {
          Serial.print("[ALT]+");
          // 例如: if (keyCode == 'x') { // 執行某個快捷操作 }
      }

      switch (keyCode) {
        case KEY_NULL: break;
        case KEY_ENTER: Serial.println(); break;
        case KEY_BACKSPACE: Serial.print("\b \b"); break;
        default:
          if (keyCode > 0 && keyCode < 200) { Serial.print(keyCode); }
          break;
      }
    }
  }
}

/**
 * @brief 核心函數：掃描鍵盤，包含水平顛倒邏輯
 */
void updateKeyboardAndLeds_TwoPulse() {
  for (int row = 0; row < 8; row++) {
    byte rowScanData = (1 << row);
    byte ledData = 0;
    digitalWrite(LATCH_PIN, LOW);
    shiftOut(DATA_OUT_PIN, CLOCK_PIN, MSBFIRST, ledData);
    shiftOut(DATA_OUT_PIN, CLOCK_PIN, MSBFIRST, rowScanData);
    digitalWrite(LATCH_PIN, HIGH); 
    delayMicroseconds(5);
    digitalWrite(LATCH_PIN, LOW);
    delayMicroseconds(1);
    digitalWrite(LATCH_PIN, HIGH);
    byte colData = myShiftIn(DATA_IN_PIN, CLOCK_PIN);
    for (int col = 0; col < 8; col++) {
      if (colData & (1 << col)) { keyState[row][7 - col] = true; } 
      else { keyState[row][7 - col] = false; }
    }
  }
}

/**
 * @brief 打印矩陣狀態 (用於除錯模式)
 */
void printKeyboardStateMatrix() {
  Serial.print("\n\n");
  Serial.println("--- Key State Matrix ---");
  Serial.println("      Cols: 0 1 2 3 4 5 6 7");
  Serial.println("      -----------------------");
  for (int r = 0; r < 8; r++) {
    Serial.print("Row "); Serial.print(r); Serial.print(": | ");
    for (int c = 0; c < 8; c++) {
      if(keyState[r][c] != lastKeyState[r][c]) { Serial.print(keyState[r][c] ? "*X " : "*_ "); } 
      else { Serial.print(keyState[r][c] ? "X " : ". "); }
    }
    Serial.println("|");
  }
  Serial.println("      -----------------------");
  Serial.print("LEDs: [1]CapsLock:"); Serial.print(isCapsLockOn ? "ON" : "OFF");
  Serial.print(" [2]Debug:"); Serial.println(debugMode ? "ON" : "OFF");
}

/**
 * @brief 自訂的 shiftIn 函數
 */
byte myShiftIn(uint8_t dataPin, uint8_t clockPin) {
  byte data = 0;
  for (int i = 0; i < 8; i++) {
    if (digitalRead(dataPin)) { data |= (1 << i); }
    digitalWrite(clockPin, HIGH);
    digitalWrite(clockPin, LOW);
  }
  return data;
}
